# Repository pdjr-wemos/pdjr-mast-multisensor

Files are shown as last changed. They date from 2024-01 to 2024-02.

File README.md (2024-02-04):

# pdjr-mast-multisensor

This project implements an
[ESP8266](https://www.espressif.com/en/products/socs/esp8266)-based
multisensor which mounts at the top of
[Beatrice](https://www.pdjr.eu/beatrice/wp-content/uploads/2021/01/beatrice.jpg)'s
mast and reports temperature, humidity, barometric pressure, lux and mast
state (raised/lowered).

The multisensor PCB is housed in a 3D printed enclosure which sits
between the mast top plate and the
[DHR35 Anchor Light](https://www.dhr.nl/dhr-marine/products/navigation-lights/dhr35).
The housing adds about 2cm to the mast height.

The PCB incorporates the following active components.

* [Wemos D1 Mini](https://www.wemos.cc/en/latest/d1/d1_mini.html)
* [Adafruit AM2320](https://www.adafruit.com/product/3721) temperature + humidity sensor
* [Bosch BMP581](https://www.bosch-sensortec.com/products/environmental-sensors/pressure-sensors/bmp581/) temperature + barometric pressure sensor
* [SW-520D](https://www.switchelectronics.co.uk/products/sw520d-ball-tilt-vibration-switch) tilt sensor
* [VEML7700](https://www.vishay.com/docs/84286/veml7700.pdf) lux sensor

The multisensor is configured and provisioned using
[ESPHome](https://esphome.io/index.html),
connects to the ships's WiFi network and integrates with the vessel's
[Home Assistant](https://www.home-assistant.io/)
platform.

<table>
  <tr>
    <td>
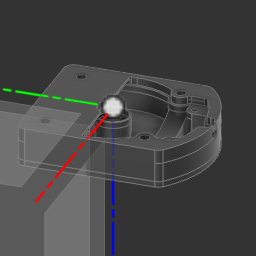
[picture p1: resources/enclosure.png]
           
    </td>
    <td>
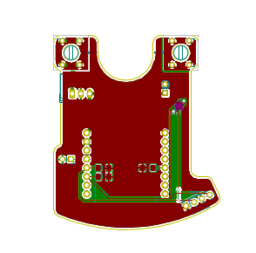
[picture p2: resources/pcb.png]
      
    </td>
  </tr>
</table>

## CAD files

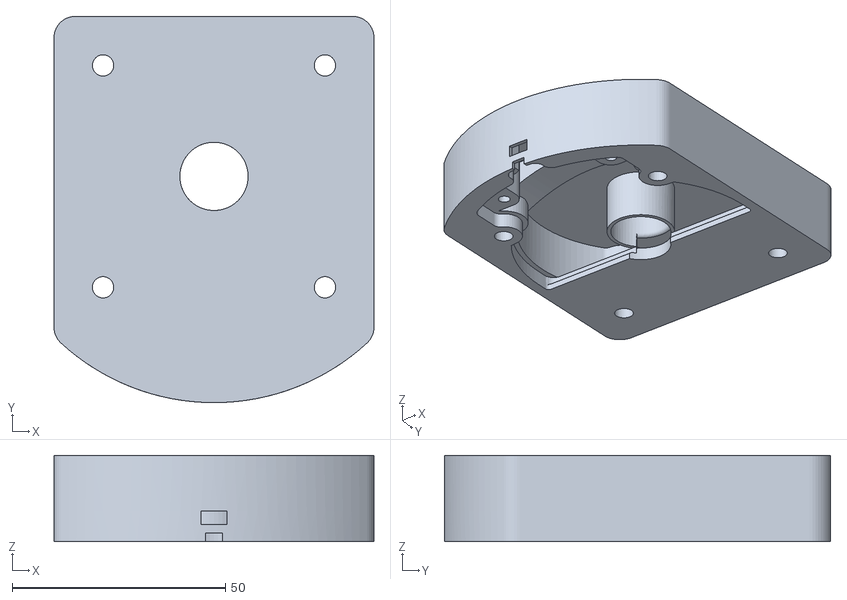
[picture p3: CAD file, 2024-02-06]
enclosure/Mast multisensor v2 v10.stl
75.0 x 90.5 x 20.2

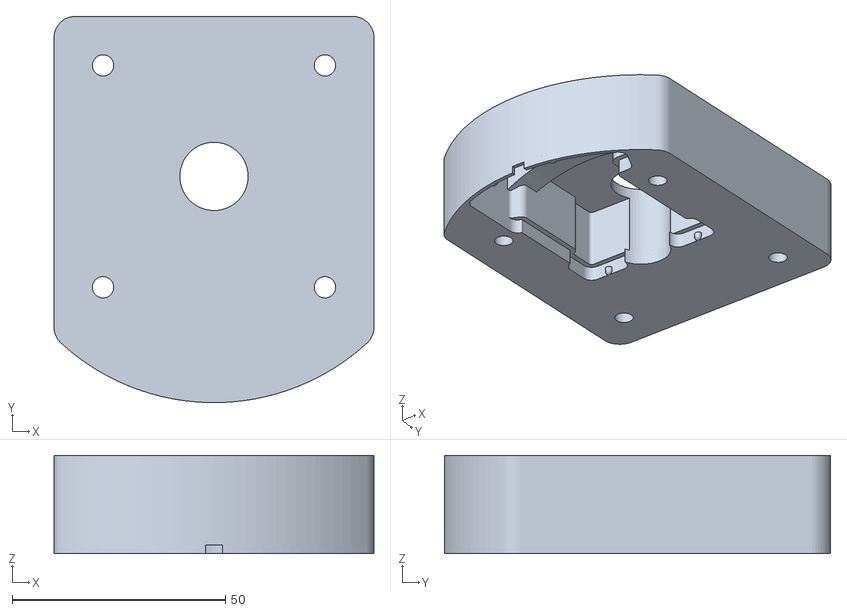
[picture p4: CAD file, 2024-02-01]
resources/mast-multisensor-enclosure.stl
75.0 x 90.5 x 23.0

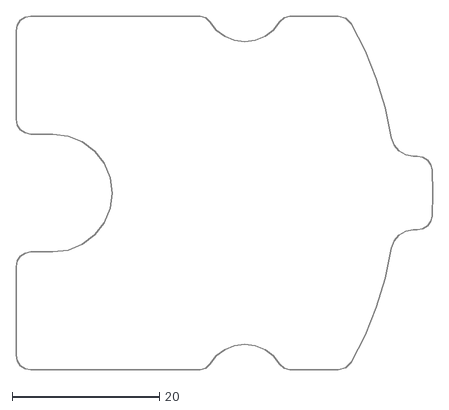
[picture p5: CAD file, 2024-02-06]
enclosure/newpcb.dxf
56.5 x 48.0

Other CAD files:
enclosure/Mast multisensor v2 v10.f3d
enclosure/Mast multisensor v2.f3d

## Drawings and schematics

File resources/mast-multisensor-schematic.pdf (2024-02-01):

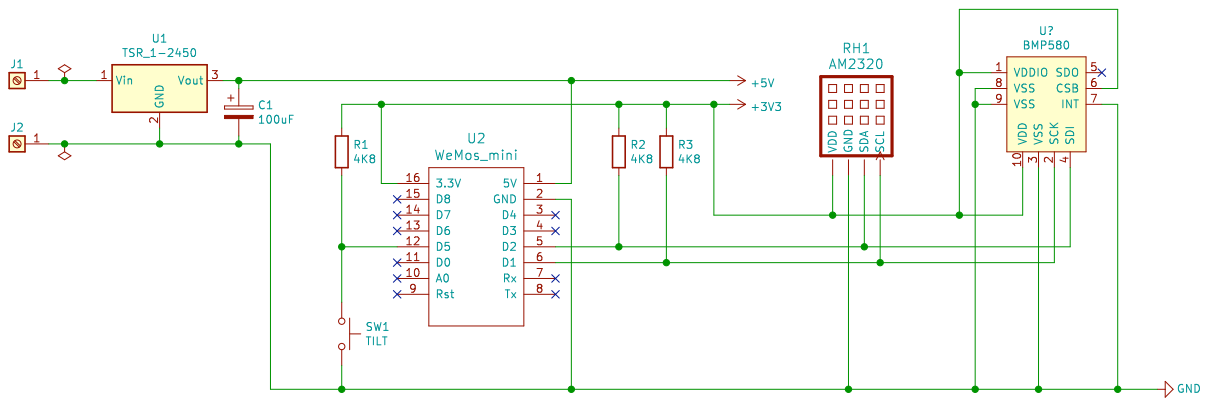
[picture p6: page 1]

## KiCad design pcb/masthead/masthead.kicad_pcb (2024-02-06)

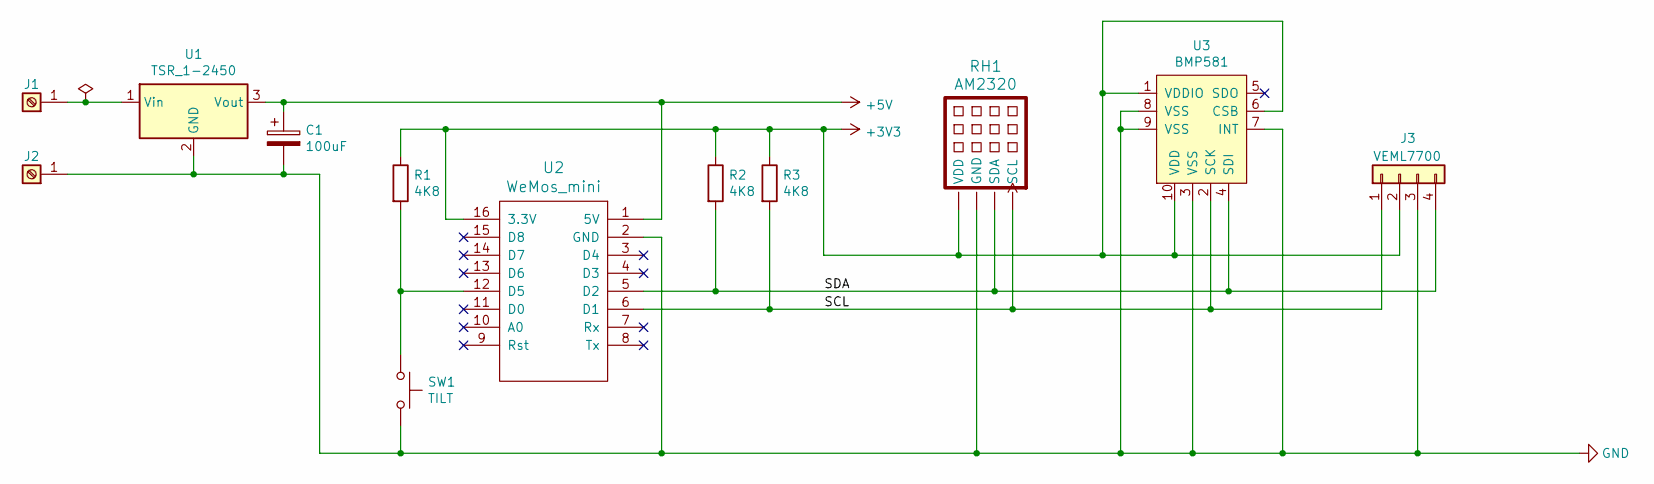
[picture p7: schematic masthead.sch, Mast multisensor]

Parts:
C1: 100uF; CP_Radial_D6.3mm_P2.50mm
J1, J2: Open screw terminal 5x7; M4_OPEN_TERMINAL
J3: VEML7700; VEML7700_SIDE
R1, R2, R3: 4K8; R_1206_3216Metric_Pad1.30x1.75mm_HandSolder
RH1: AM2320; AM2320_HORIZ
SW1: TILT; PinSocket_1x02_P2.54mm_Vertical
U1: TSR_1-2450; Converter_DCDC_TRACO_TSR-1_THT
U2: WeMos_mini; Wemos_D1_mini
U3: BMP581

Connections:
+3V3: J3.2, R1.1, R2.1, R3.1, RH1.1 (VDD), U2.16 (3.3V), U3.1 (VDDIO), U3.6 (CSB), U3.10 (VDD)
+5V: C1.1, U1.3 (Vout), U2.1 (5V)
/SCL: J3.1, R3.2, RH1.4 (SCL), U2.6 (D1), U3.2 (SCK)
/SDA: J3.4, R2.2, RH1.2 (SDA), U2.5 (D2), U3.4 (SDI)
GND: C1.2, J2.1, J3.3, RH1.3 (GND), SW1.2, U1.2 (GND), U2.2 (GND), U3.3 (VSS), U3.7 (INT), U3.8 (VSS), U3.9 (VSS)
unnamed: J1.1, U1.1 (Vin)
unnamed: R1.2, SW1.1, U2.12 (D5)

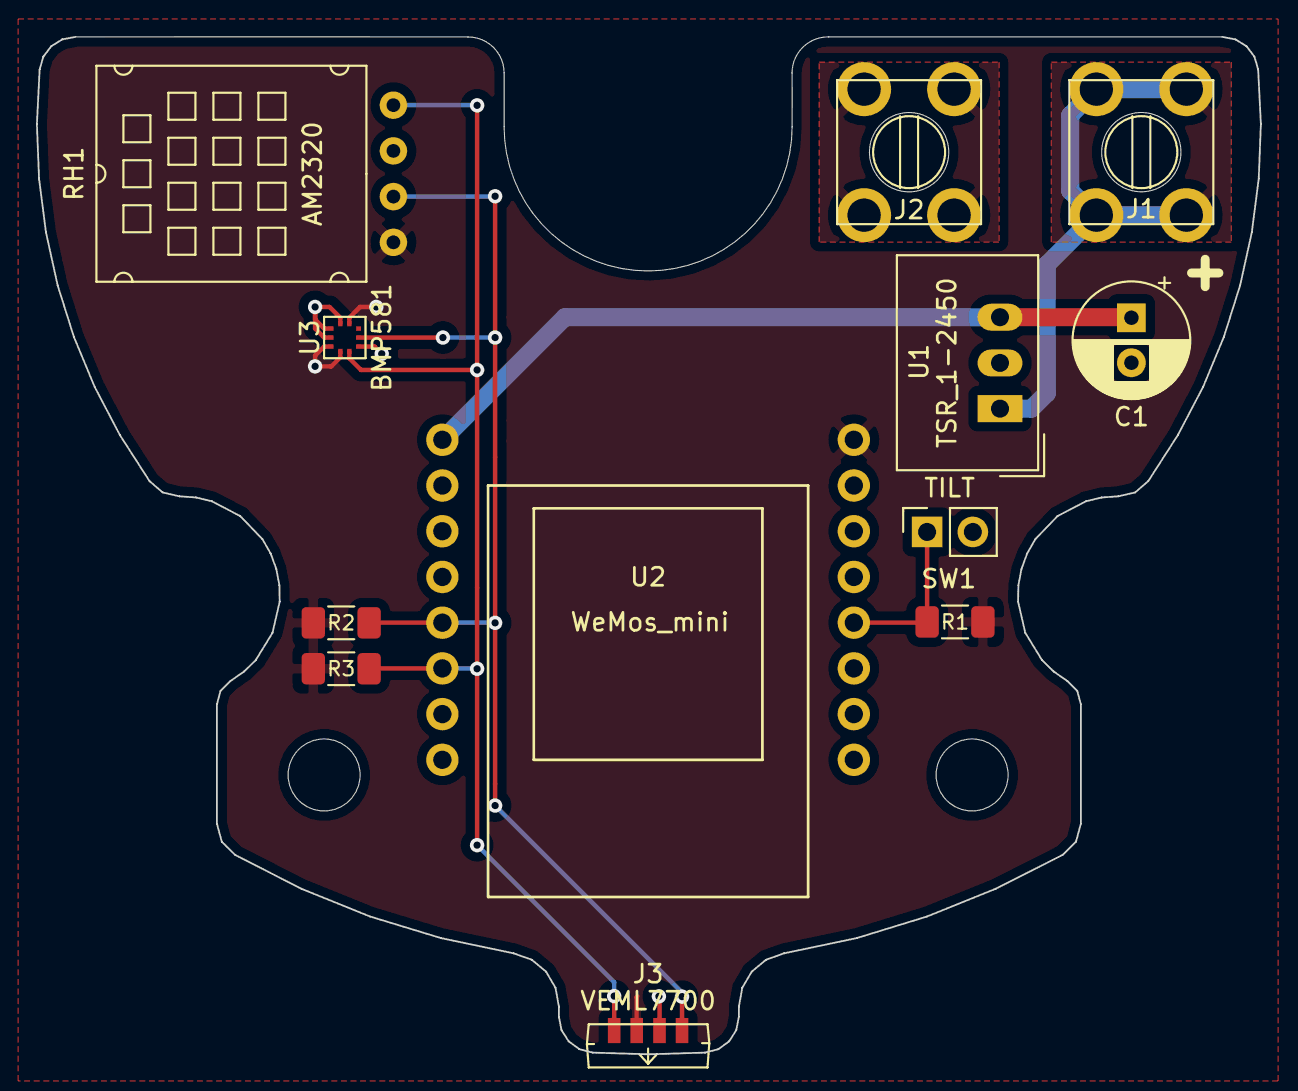
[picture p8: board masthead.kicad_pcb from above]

Board: 2 copper layers, 68.0 x 56.5 mm, 12 parts (1 on the bottom side), 7 nets.

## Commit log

2024-01-30 First upload
    [masthead.kicad_pcb, masthead.sch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]
2024-02-01 Add stl
    [mast-multisensor-enclosure.stl]
2024-02-02 PCB tweak
    [masthead.kicad_pcb, masthead.sch]
2024-02-04 Add VEML7700
    [masthead.kicad_pcb, masthead.sch]
2024-02-06 New version of enclosure
    [masthead.kicad_pcb]
